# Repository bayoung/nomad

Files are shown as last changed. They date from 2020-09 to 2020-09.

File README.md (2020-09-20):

# Nomad

Keyboard for Digital Nomads

# Config and Build Firmware

* cd nomad
* git clone git@github.com:bayoung/qmk_firmware.git
* git checkout brian.young/nomad
* cd qmk_firmware
* git submodule sync --recursive
* git submodule update --init --recursive --progress
* make nomad:default
* run teensy.app
* select qmk_firmware/nomad_default.hex
* press reset on Keyboard (or Fn-Esc if there's good firmware running)
* load
* replug USB cable on keyboard

# PCB

* cd pcb
* git clone git@github.com:keebio/Keebio-Parts.pretty.git
* cd Keebio-Parts.pretty
* git checkout aec652e40624d7872b2659f307ac483922ba315f
* cd ..
* git clone git@github.com:XenGi/teensy_library.git
* git checkout 14f5629c7d822ed95580319626f745de2a11fefd
* cd ..
* open NomadLeft / NomadRight in KiCad

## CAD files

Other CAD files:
enclosure/Folding Enclosures v42.f3z

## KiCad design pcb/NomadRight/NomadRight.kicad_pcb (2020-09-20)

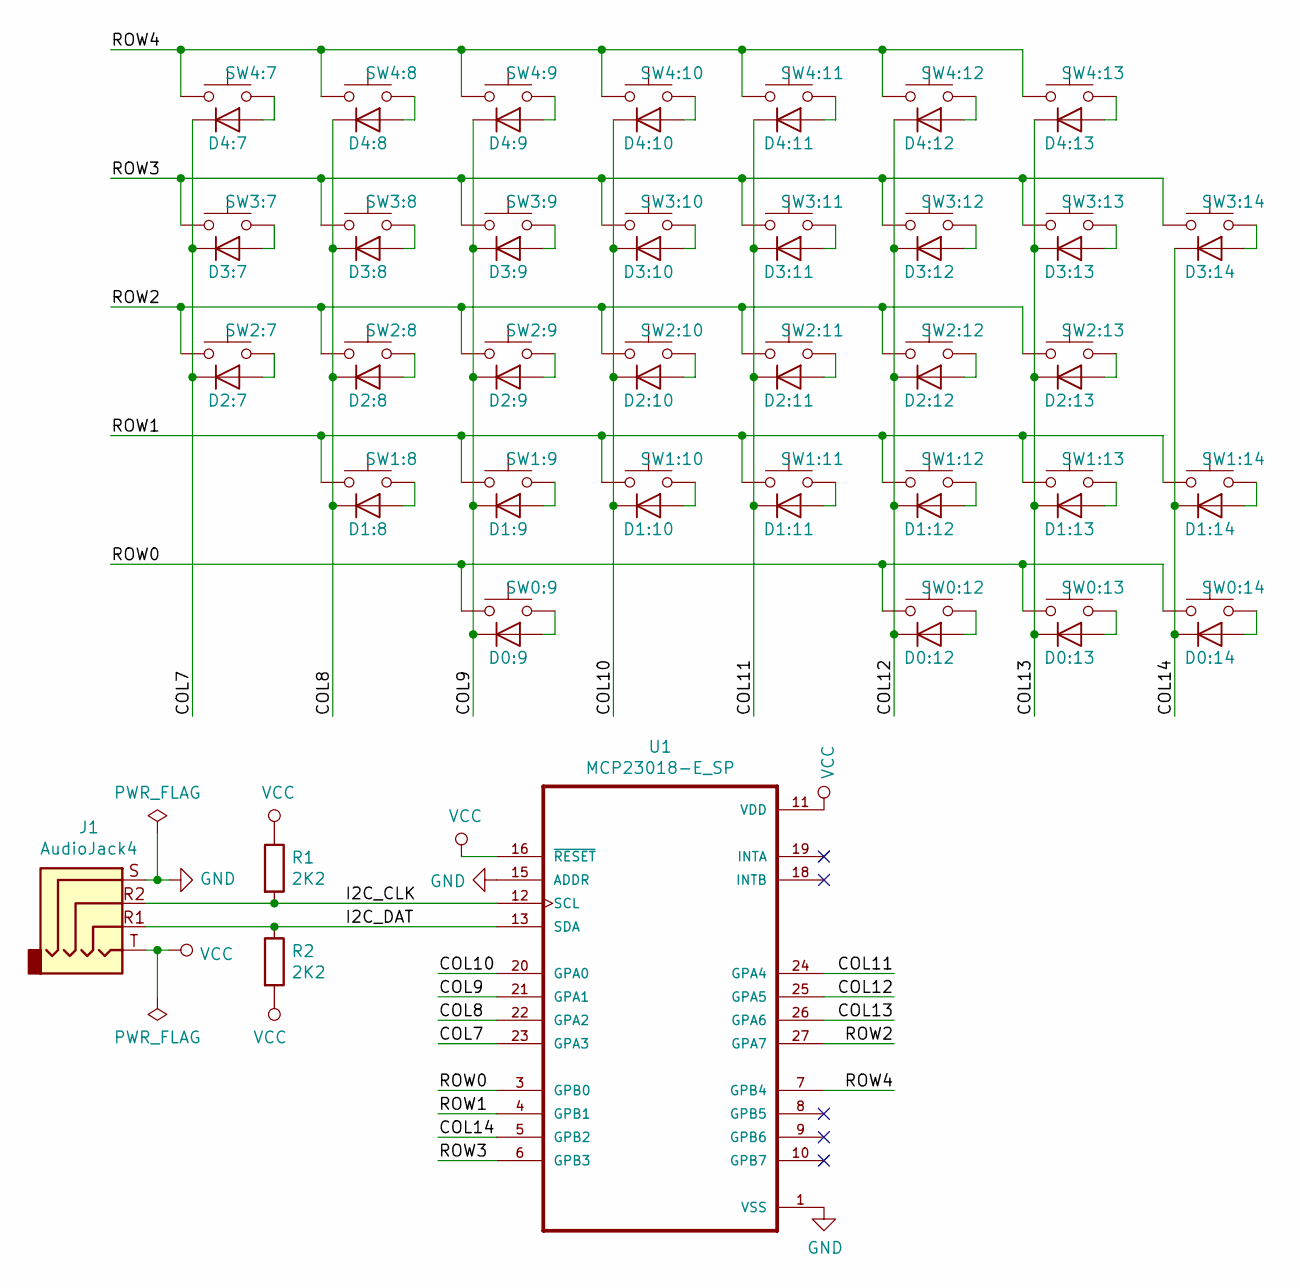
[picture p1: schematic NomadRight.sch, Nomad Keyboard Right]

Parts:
D0:9, D0:12, D0:13, D0:14, D1:8, D1:9, D1:10, D1:11, D1:12, D1:13, D1:14, D2:7, D2:8, D2:9, D2:10, D2:11, D2:12, D2:13, D3:7, D3:8, D3:9, D3:10, D3:11, D3:12, D3:13, D3:14, D4:7, D4:8, D4:9, D4:10, D4:11, D4:12, D4:13: 1N4148TR; D_DO-35_SOD27_P7.62mm_Horizontal
J1: AudioJack4; CUI_SJ-43514
R1, R2: 2K2; R_0805_2012Metric_Pad1.15x1.40mm_HandSolder
SW0:9, SW0:12, SW0:13, SW0:14, SW1:8, SW1:9, SW1:10, SW1:11, SW1:12, SW1:13, SW1:14, SW2:7, SW2:8, SW2:9, SW2:10, SW2:11, SW2:12, SW2:13, SW3:7, SW3:8, SW3:9, SW3:10, SW3:11, SW3:12, SW3:13, SW3:14, SW4:7, SW4:8, SW4:9, SW4:10, SW4:11, SW4:12, SW4:13: SW_Push; Kailh-PG1350-1u
U1: MCP23018-E_SP; DIP-28_W7.62mm

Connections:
/COL7: D2:7.1 (K), D3:7.1 (K), D4:7.1 (K), U1.23 (GPA3)
/COL8: D1:8.1 (K), D2:8.1 (K), D3:8.1 (K), D4:8.1 (K), U1.22 (GPA2)
/COL9: D0:9.1 (K), D1:9.1 (K), D2:9.1 (K), D3:9.1 (K), D4:9.1 (K), U1.21 (GPA1)
/COL10: D1:10.1 (K), D2:10.1 (K), D3:10.1 (K), D4:10.1 (K), U1.20 (GPA0)
/COL11: D1:11.1 (K), D2:11.1 (K), D3:11.1 (K), D4:11.1 (K), U1.24 (GPA4)
/COL12: D0:12.1 (K), D1:12.1 (K), D2:12.1 (K), D3:12.1 (K), D4:12.1 (K), U1.25 (GPA5)
/COL13: D0:13.1 (K), D1:13.1 (K), D2:13.1 (K), D3:13.1 (K), D4:13.1 (K), U1.26 (GPA6)
/COL14: D0:14.1 (K), D1:14.1 (K), D3:14.1 (K), U1.5 (GPB2)
/I2C_CLK: J1.R2, R1.2, U1.12 (SCL)
/I2C_DAT: J1.R1, R2.1, U1.13 (SDA)
/ROW0: SW0:9.1, SW0:12.1, SW0:13.1, SW0:14.1, U1.3 (GPB0)
/ROW1: SW1:8.1, SW1:9.1, SW1:10.1, SW1:11.1, SW1:12.1, SW1:13.1, SW1:14.1, U1.4 (GPB1)
/ROW2: SW2:7.1, SW2:8.1, SW2:9.1, SW2:10.1, SW2:11.1, SW2:12.1, SW2:13.1, U1.27 (GPA7)
/ROW3: SW3:7.1, SW3:8.1, SW3:9.1, SW3:10.1, SW3:11.1, SW3:12.1, SW3:13.1, SW3:14.1, U1.6 (GPB3)
/ROW4: SW4:7.1, SW4:8.1, SW4:9.1, SW4:10.1, SW4:11.1, SW4:12.1, SW4:13.1, U1.7 (GPB4)
GND: J1.S, U1.1 (VSS), U1.15 (ADDR)
unnamed: D0:9.2 (A), SW0:9.2
unnamed: D0:12.2 (A), SW0:12.2
unnamed: D0:13.2 (A), SW0:13.2
unnamed: D0:14.2 (A), SW0:14.2
unnamed: D1:8.2 (A), SW1:8.2
unnamed: D1:9.2 (A), SW1:9.2
unnamed: D1:10.2 (A), SW1:10.2
unnamed: D1:11.2 (A), SW1:11.2
unnamed: D1:12.2 (A), SW1:12.2
unnamed: D1:13.2 (A), SW1:13.2
unnamed: D1:14.2 (A), SW1:14.2
unnamed: D2:7.2 (A), SW2:7.2
unnamed: D2:8.2 (A), SW2:8.2
unnamed: D2:9.2 (A), SW2:9.2
unnamed: D2:10.2 (A), SW2:10.2
unnamed: D2:11.2 (A), SW2:11.2
unnamed: D2:12.2 (A), SW2:12.2
unnamed: D2:13.2 (A), SW2:13.2
unnamed: D3:7.2 (A), SW3:7.2
unnamed: D3:8.2 (A), SW3:8.2
unnamed: D3:9.2 (A), SW3:9.2
unnamed: D3:10.2 (A), SW3:10.2
unnamed: D3:11.2 (A), SW3:11.2
unnamed: D3:12.2 (A), SW3:12.2
unnamed: D3:13.2 (A), SW3:13.2
unnamed: D3:14.2 (A), SW3:14.2
unnamed: D4:7.2 (A), SW4:7.2
unnamed: D4:8.2 (A), SW4:8.2
unnamed: D4:9.2 (A), SW4:9.2
unnamed: D4:10.2 (A), SW4:10.2
unnamed: D4:11.2 (A), SW4:11.2
unnamed: D4:12.2 (A), SW4:12.2
unnamed: D4:13.2 (A), SW4:13.2
VCC: J1.T, R1.1, R2.2, U1.11 (VDD), U1.16 (~RESET~)

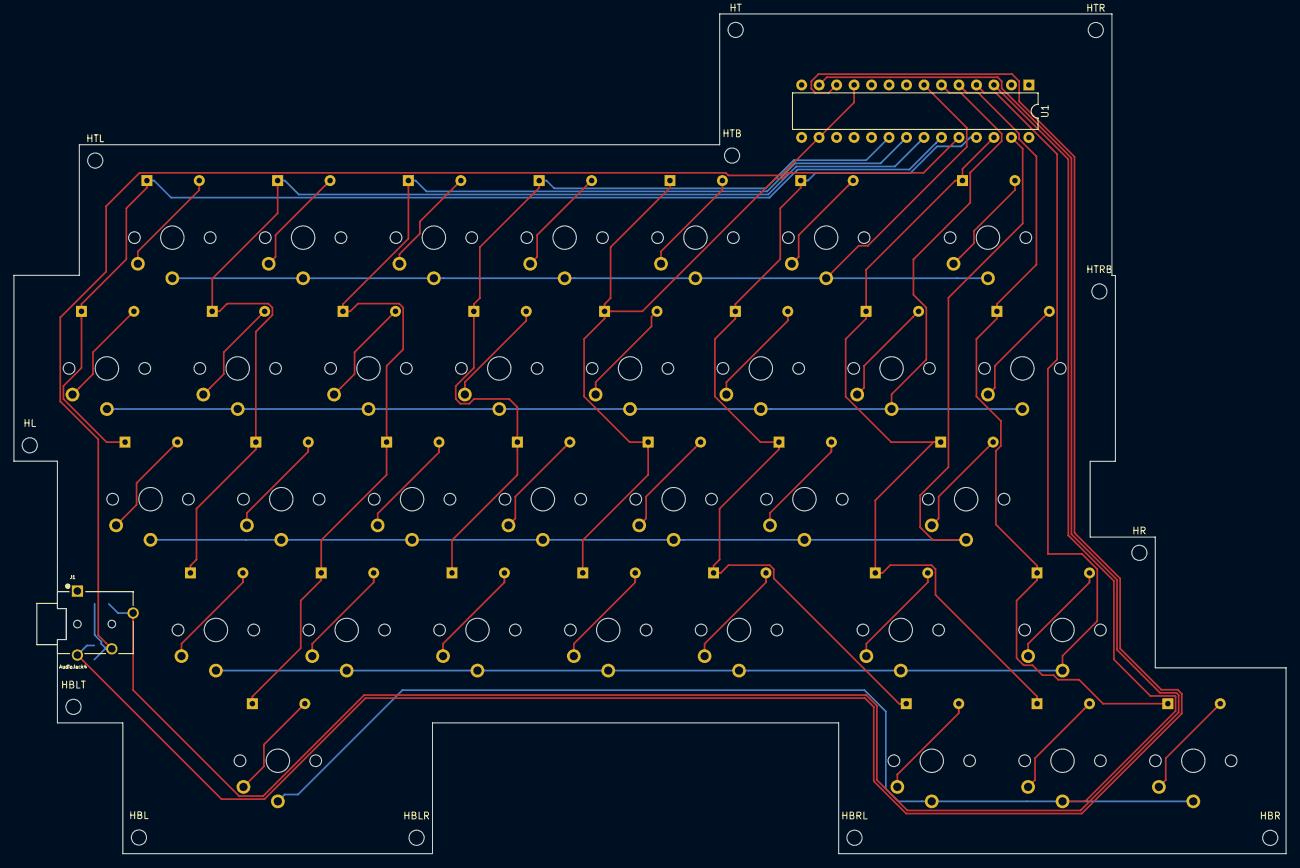
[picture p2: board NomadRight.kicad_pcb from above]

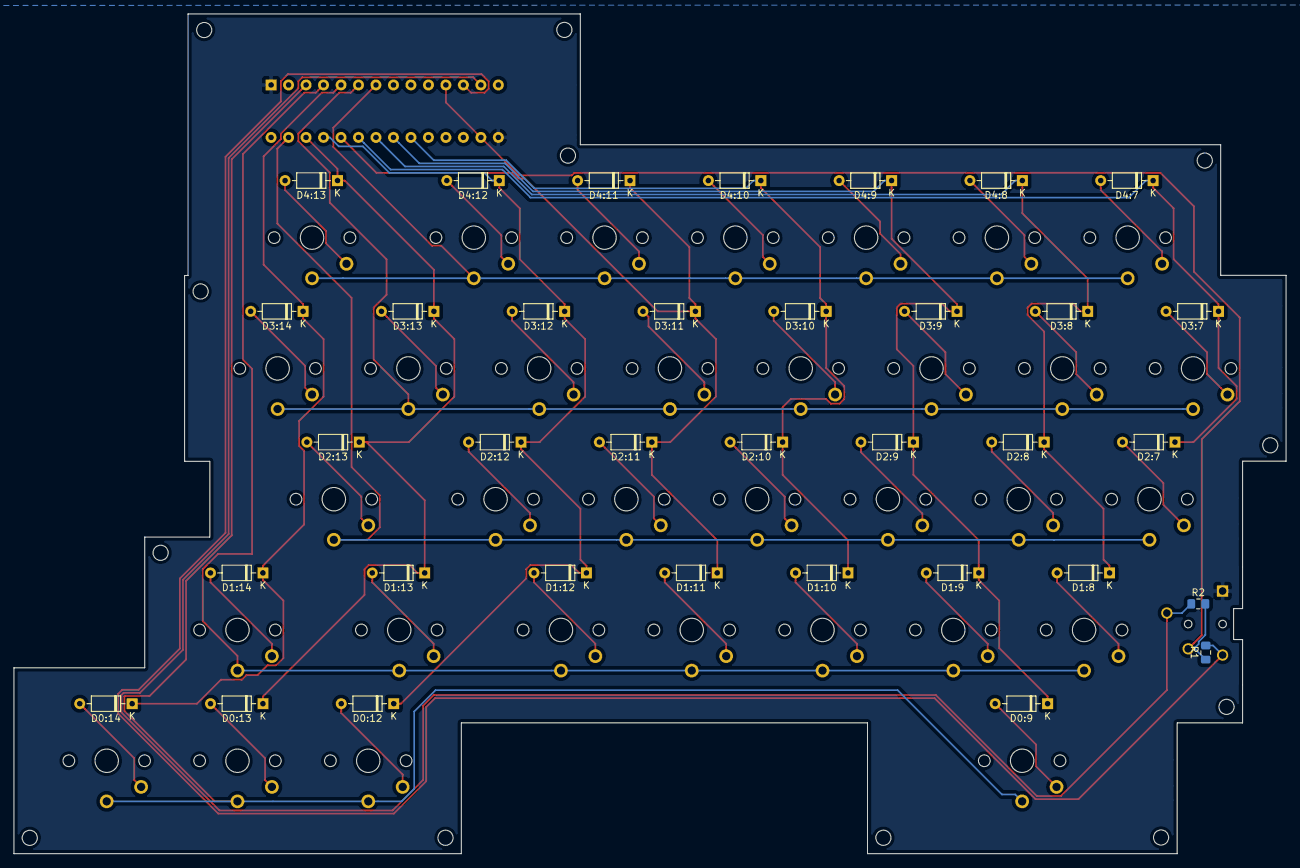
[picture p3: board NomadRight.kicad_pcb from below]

Board: 2 copper layers, 184.8 x 122.0 mm, 82 parts (35 on the bottom side), 50 nets.

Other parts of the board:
HBL: MountingHole_2.2mm_M2
HBLR: MountingHole_2.2mm_M2
HBLT: MountingHole_2.2mm_M2
HBR: MountingHole_2.2mm_M2
HBRL: MountingHole_2.2mm_M2
HL: MountingHole_2.2mm_M2
HR: MountingHole_2.2mm_M2
HT: MountingHole_2.2mm_M2
HTB: MountingHole_2.2mm_M2
HTL: MountingHole_2.2mm_M2
HTR: MountingHole_2.2mm_M2
HTRB: MountingHole_2.2mm_M2

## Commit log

2020-09-20 Add PCB files
    [Nomad-B_Cu.gbr, Nomad-B_Mask.gbr, Nomad-B_SilkS.gbr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]
2020-09-21 Fusion 360 model for the folding enclosure.
    [Folding Enclosures v42.f3z]
2020-10-26 Fix schematics by rescuing symbols.
    [Nomad.sch]
